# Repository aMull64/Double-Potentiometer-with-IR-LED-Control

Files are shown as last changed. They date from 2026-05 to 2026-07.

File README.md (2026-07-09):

## Problem Formulation
  This project is an extension of a pre-existing product, that being a Logitech Z313 Speaker System with Subwoofer [1]. This speaker system is wired as the output to a Sony TV, one that can be controlled with a wireless controller, but does not respond to volume up or volume down. This is okay because the Logitech speakers do not work with the TV volume. The Logitech speakers control their volume by manually controlling a potentiometer. I would like the ability to control the volume remotely. The TV remote not controlling the TV volume works with us in this case; we can read the IR signals coming from the remote with an IR sensor and adjust the potentiometers to control the volume.
  
  The pre-existing circuit can be seen in Circuit_Board_Scale, and the wires we will be working with can be seen in Circuit_Board_Connectors.
  
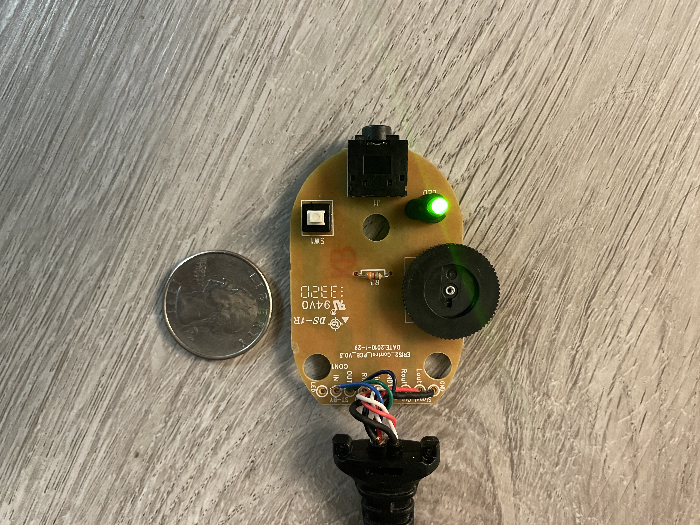
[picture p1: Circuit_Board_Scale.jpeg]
Circuit_Board_Scale: a picture of the circuit next to a quarter

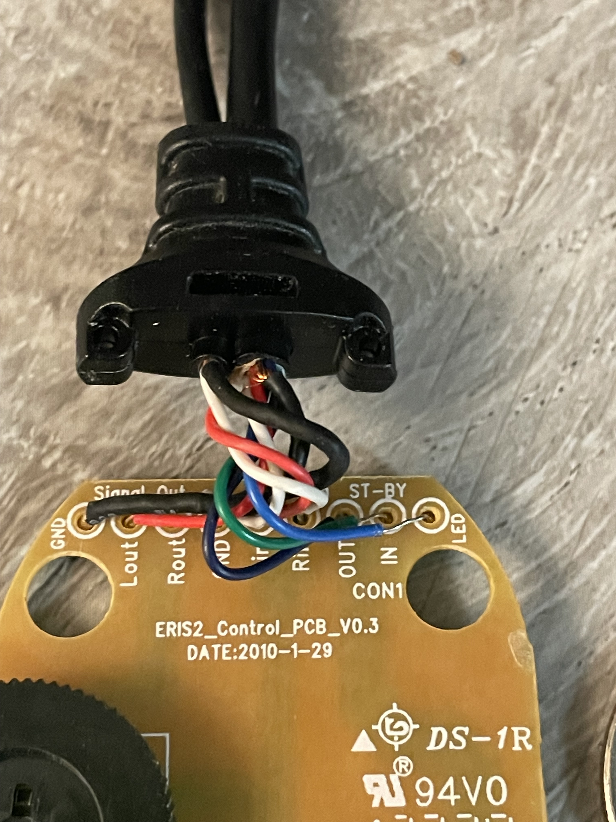
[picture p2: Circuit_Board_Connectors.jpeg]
Circuit_Board_Connectors: a picture of the circuit revealing the pin placements


The pins go as follows: GND, Lout, Rout, GND, Lin, Rin, OUT, IN, LED. Looking at the back reveals that both grounds are connected to each other, creating a common ground.
- Lout and Rout are the left and right channels post-potentiometer
- Lin and Rin are the left and right channels pre-potentiometer
- OUT and IN seem to be used as a way to tell if the system is on or off. They are connected through the dbdt switch and nothing else.
- LED is the power that goes to the LED; we might be able to tap into this power for the integrated circuits. 12V

## Proposed Solution
  In order to read IR signals, we need to include a microcontroller, but in order to choose one, we need to know what else is needed. 2 physical buttons will take the place of the current physical potentiometer, which changes the internal volume variable. And an RGB LED to determine when the system is powered, this can also be used as a debugging tool, changing colors when changing internal variables. 2 digital potentiometers are used to adjust the left and right channel, controlled through I2C. A DBDT switch will be used to control the "power" LED signifier, connect the standby OUT and IN, and introduce power to the rest of the system. The microcontroller in question will need 2 pins for I2C communication (and the ability to do that), 2 pins for manual control (2 buttons), 2 pins for the LED (Blue and Green), and 1 pin for the IR Sensor. In total, we need 7 usable pins, and the ATtiny 404 will fit our case [2]. We will include 2 digital potentiometers that are controlled with I2C 

##  Version 1:
  The first iteration was successful in communicating with the digital potentiometers through I2C. The programming for the experimental stage gave complete control to the RBG LED, the 2 Digital Potentiometers, the ability to read the IR signals from the remote, and the ability to compile the program within the 4kB flash memory limit. This came with the problem of not reading enough datasheets. After further examination of the digital potentiometer datasheet, it does not appreciate negative voltage through the two terminals (which audio covers a range of about [-2.5, 2.5]). This led to some complications and created a design that fundamentally did not work.

##  Version 2:
  The issue was tackled by using a coupling capacitor within a voltage divider to shift the range into a completely positive voltage [0, 5]. The side buttons were removed because they were virtually inaccessible when the casing was completely put on. A different voltage regulator was used that established a 5V rail, which is how the voltage divider was allowed to work.

  

## References
[1] https://www.logitech.com/en-us/shop/p/z313-speaker-system-subwoofer.980-000382 

[2] https://www.digikey.com/en/products/detail/microchip-technology/ATTINY404-SSNR/8594960

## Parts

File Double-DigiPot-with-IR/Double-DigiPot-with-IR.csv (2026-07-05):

Id | Designator | Footprint | Quantity | Designation | Supplier and ref
1 | C1, C2, C3, C4 | C_0805_2012Metric_Pad1.18x1.45mm_HandSolder | 4 | 100n
2 | C5, C6, C7, C8, C9, C10 | C_0805_2012Metric_Pad1.18x1.45mm_HandSolder | 6 | 10u
3 | D1 | LED_D5.0mm-4_RGB_Staggered_Pins | 1 | LED_RKGB
4 | J1 | PinSocket_1x09_P2.54mm_Vertical | 1 | Conn_01x09_Pin
5 | R1, R2, R3 | R_0805_2012Metric_Pad1.20x1.40mm_HandSolder | 3 | 330
6 | R4, R5, R6 | R_0805_2012Metric_Pad1.20x1.40mm_HandSolder | 3 | 4.7k
7 | R7, R8, R9, R10, R11, R12 | R_0805_2012Metric_Pad1.20x1.40mm_HandSolder | 6 | 10k
8 | SW1 | CONN_S2273_APM | 1 | SW_Push_DPDT
9 | TP1, TP2 | TestPoint_Pad_D4.0mm | 2 | TestPoint
10 | TP3 | TestPoint_Pad_D4.0mm | 1 | GNDPoint
11 | U1 | SOIC-14_3.9x8.7mm_P1.27mm | 1 | ATtiny404-SS
12 | U2, U3 | MSOP8_MC_MCH | 2 | MCP4561T-103E/MS
13 | U4 | Vishay_MINICAST-3Pin | 1 | TSOP382xx
14 | U6 | SOT-89-3_Handsoldering | 1 | MC78L05_SOT89

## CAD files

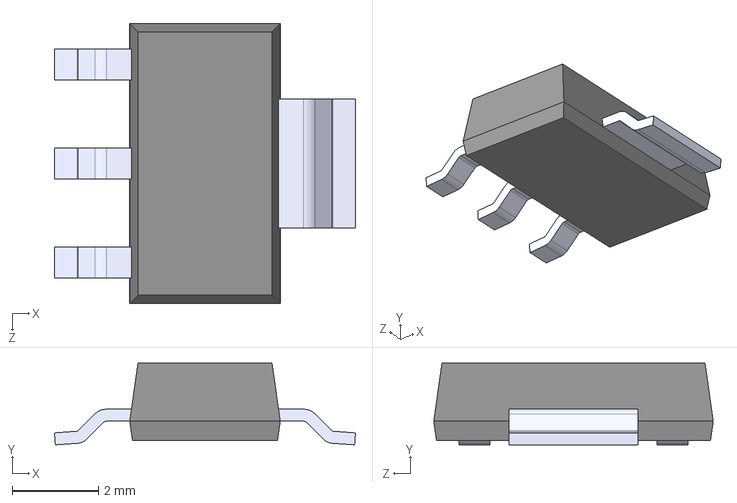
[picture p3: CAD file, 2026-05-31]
Double-DigiPot-with-IR/KiCADv6/TS1117BCW33_RPG.step
7.00 x 1.90 x 6.50 mm

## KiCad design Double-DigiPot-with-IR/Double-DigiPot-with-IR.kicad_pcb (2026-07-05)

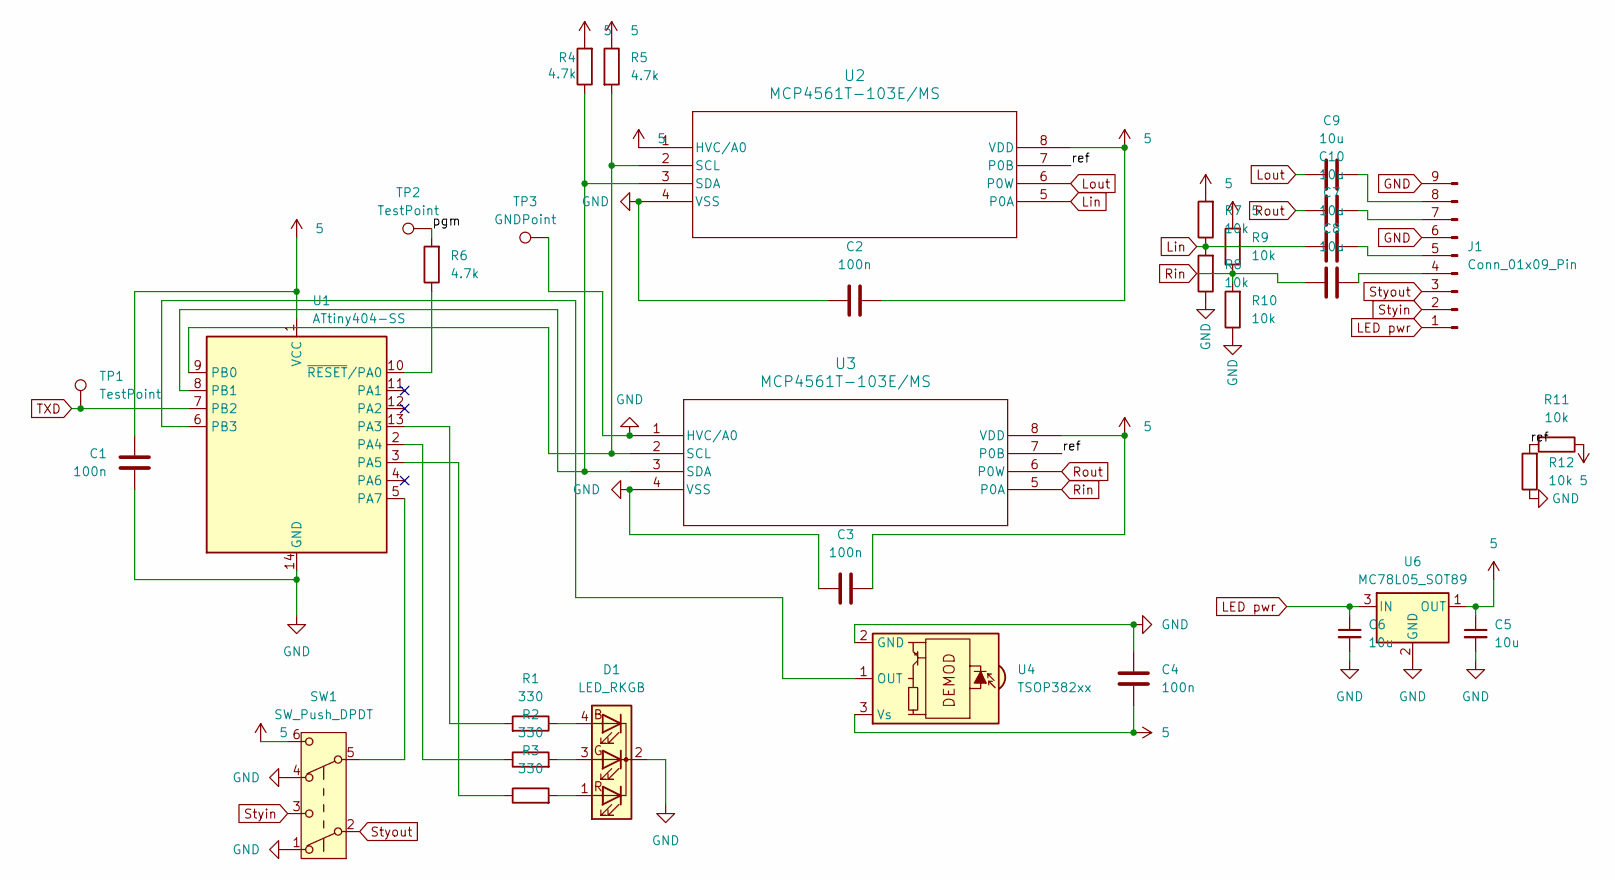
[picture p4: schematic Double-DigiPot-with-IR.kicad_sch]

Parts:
C1, C2, C3, C4: 100n; C_0805_2012Metric_Pad1.18x1.45mm_HandSolder
C5, C6, C7, C8, C9, C10: 10u; C_0805_2012Metric_Pad1.18x1.45mm_HandSolder
D1: LED_RKGB; LED_D5.0mm-4_RGB_Staggered_Pins
J1: Conn_01x09_Pin; PinSocket_1x09_P2.54mm_Vertical
R1, R2, R3: 330; R_0805_2012Metric_Pad1.20x1.40mm_HandSolder
R4, R5, R6: 4.7k; R_0805_2012Metric_Pad1.20x1.40mm_HandSolder
R7, R8, R9, R10, R11, R12: 10k; R_0805_2012Metric_Pad1.20x1.40mm_HandSolder
SW1: SW_Push_DPDT; CONN_S2273_APM
TP1, TP2: TestPoint; TestPoint_Pad_D4.0mm
TP3: GNDPoint; TestPoint_Pad_D4.0mm
U1: ATtiny404-SS; SOIC-14_3.9x8.7mm_P1.27mm
U2, U3: MCP4561T-103E/MS; MSOP8_MC_MCH
U4: TSOP382xx; Vishay_MINICAST-3Pin
U6: MC78L05_SOT89; SOT-89-3_Handsoldering

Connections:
5: C1.1, C2.2, C3.2, C4.1, C5.1, R4.2, R5.1, R7.2, R9.2, R11.1, SW1.6 (C), U1.1 (VCC), U2.1 (HVC/A0), U2.8 (VDD), U3.8 (VDD), U4.3 (Vs), U6.1 (OUT)
/pgm: R6.2, TP2.1 (1_1)
/ref: R11.2, R12.2, U2.7 (P0B), U3.7 (P0B)
GND: C1.2, C2.1, C3.1, C4.2, C5.2, C6.2, D1.2 (K), J1.6, J1.9, R8.1, R10.1, R12.1, SW1.1 (A), SW1.4 (A), TP3.1 (1_1), U1.14 (GND), U2.4 (VSS), U3.1 (HVC/A0), U3.4 (VSS), U4.2 (GND), U6.2 (GND)
LED pwr: C6.1, J1.1, U6.3 (IN)
Lin: C7.1, R7.1, R8.2, U2.5 (P0A)
Lout: C9.1, U2.6 (P0W)
unnamed: D1.4 (BA), R1.1
unnamed: D1.3 (GA), R2.2
unnamed: D1.1 (RA), R3.2
unnamed: C8.2, J1.4
unnamed: C7.2, J1.5
unnamed: C10.2, J1.7
unnamed: C9.2, J1.8
unnamed: R1.2, U1.13 (PA3)
unnamed: R2.1, U1.2 (PA4)
unnamed: R3.1, U1.3 (PA5)
unnamed: SW1.5 (B), U1.5 (PA7)
unnamed: R5.2, U1.9 (PB0), U2.2 (SCL), U3.2 (SCL)
unnamed: R4.1, U1.8 (PB1), U2.3 (SDA), U3.3 (SDA)
unnamed: U1.6 (PB3), U4.1 (OUT)
unnamed: R6.1, U1.10 (~RESET/PA0)
Rin: C8.1, R9.1, R10.2, U3.5 (P0A)
Rout: C10.1, U3.6 (P0W)
Styin: J1.2, SW1.3 (C)
Styout: J1.3, SW1.2 (B)
TXD: TP1.1 (1_1), U1.7 (PB2)

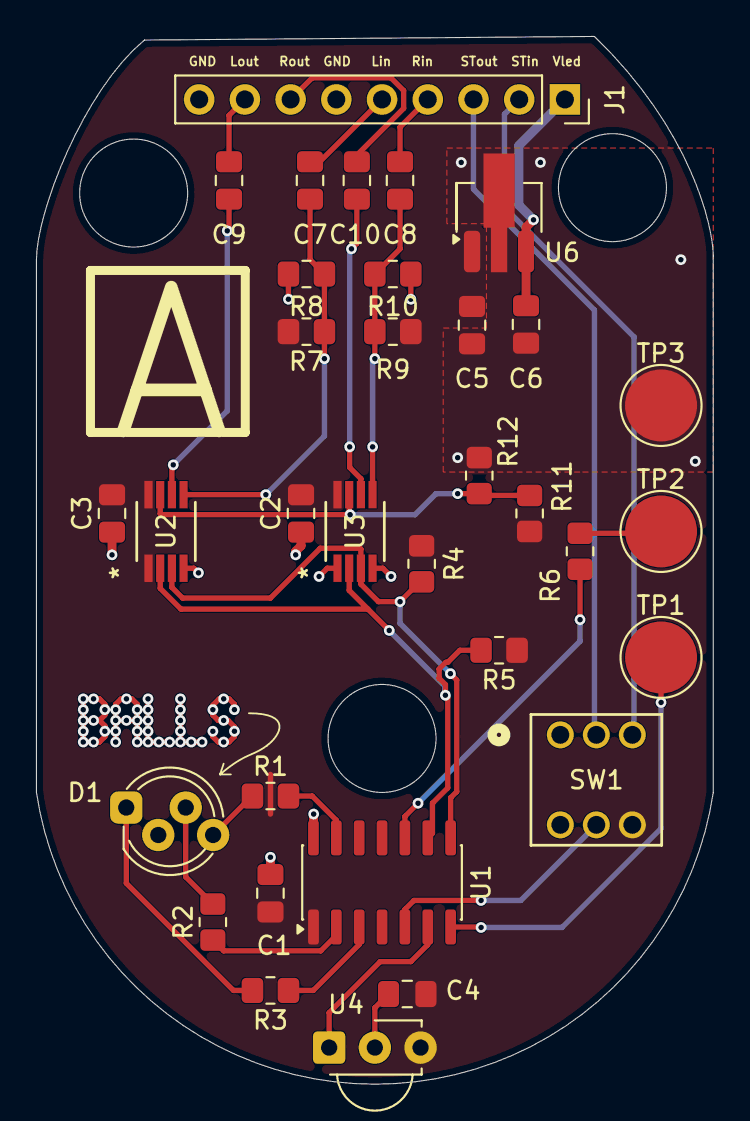
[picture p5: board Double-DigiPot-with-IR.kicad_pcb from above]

Board: 2 copper layers, 37.6 x 58.2 mm, 33 parts (0 on the bottom side), 27 nets.

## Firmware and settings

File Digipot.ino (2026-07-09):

#include <Wire.h>
#include <avr/io.h>
#include <avr/interrupt.h>

//#define DEBUG

#define POWER_STATUS_PIN (8)
#define RED_LED_PIN (2)
#define BLUE_LED_PIN (3)
#define SENSOR_PIN (4)

#define RED_LED_bm (PIN4_bm)
#define BLUE_LED_bm (PIN5_bm)

#define SENSOR_bm (PIN3_bm)
#define SENSOR_pos (3)

#define MIN_SAMPLES_0 (1)
#define MIN_SAMPLES_1 (5)
#define MAX_SAMPLES_0 (4)
#define MAX_SAMPLES_1 (8)
#define MIN_SAMPLES_START (9)
#define MAX_SAMPLES_START (50)

#define NUM_BITS (12)

#define VOL_UP_CMD (0x490)
#define VOL_DOWN_CMD (0xC90)
#define VOL_MUTE (0x290)
#define IR_DOWNTIME (500)

#define LED_ON_TICKS (1000)
#define MAX_COMBO (30)

volatile uint8_t vol = 1;
volatile uint8_t mute_flag = 0;
volatile uint8_t sent_vol = 0;

// Your register address, which can be found on your IC's datasheet
#define SUB_0_ADDR 0x2E //please correct me if wrong, datasheet says '0101 11'b + A0 = 0010 111 (0 or 1)
#define SUB_1_ADDR 0x2F
#define WRITE_CMD 0x00

/*Pinouts:
(11)PA0 = programming Pin
(8)PA1 = Power Data Input
(0)PA4 = LED Red
(1)PA5 = LED Blue
(2)PA6 = Volume Up Pushbutton
(3)PA7 = Volume Down Pushbutton

(7)PB0 = SCL
(6)PB1 = SDA
(5)PB2 = TestPoint
(4)PB3 = IRLED
*/

ISR(TCA0_OVF_vect) {
    static volatile uint8_t samp_count = 0;
    static volatile uint8_t bit_count = 0;
    static volatile uint16_t cmd_buffer = 0x00;

    static volatile uint16_t red_led_on_ticks = 0;
    static volatile uint16_t blue_led_on_ticks = 0;

    static volatile uint16_t on_ticks = 0;
    static volatile uint8_t combo_meter = 0;

    static volatile uint16_t last_cmd = 0;

    uint8_t sensor_state = (PORTB.IN & SENSOR_bm) >> SENSOR_pos;

    if (sensor_state) {
      // Check to see if we just got high
      if(on_ticks <= IR_DOWNTIME){
        ++on_ticks;
        if(on_ticks == IR_DOWNTIME){
          combo_meter = 0;
        }
      }

      if (samp_count) {
        if (bit_count <= NUM_BITS)
          ++bit_count;

        if (samp_count > MIN_SAMPLES_0 && samp_count <= MAX_SAMPLES_0) {
          // I guess we do nothing
        }
        else if (samp_count > MIN_SAMPLES_1 && samp_count <= MAX_SAMPLES_1) {
          cmd_buffer |= (1 << (NUM_BITS - bit_count));
        }
        else if(samp_count > MIN_SAMPLES_START && samp_count <= MAX_SAMPLES_START) {
          // We got a start bit
          cmd_buffer = 0x00;
          bit_count = 0;
        }

        // Check how many bits we got
        if (bit_count == NUM_BITS) {
          if (last_cmd == cmd_buffer) {
            if (combo_meter < MAX_COMBO)
              ++combo_meter;
          }

          else {
            combo_meter = 0;
          }

          last_cmd = cmd_buffer;

          if (cmd_buffer == VOL_UP_CMD && vol < 255) {
            mute_flag = 0;

            if (combo_meter == MAX_COMBO) {
              vol = vol < 250 ? vol + 5 : 255;
            } else ++vol;

            red_led_on_ticks = LED_ON_TICKS;
          }

          else if (cmd_buffer == VOL_DOWN_CMD && vol > 0) {
            mute_flag = 0;

            if (combo_meter == MAX_COMBO) {
              vol = vol > 5 ? vol - 5 : 0;
            } else --vol;

            blue_led_on_ticks = LED_ON_TICKS;
          }

          else if (cmd_buffer == VOL_MUTE) {
            if (combo_meter == 1) {
              mute_flag = !mute_flag;
            }
          }
            
#ifdef DEBUG
          Serial.print("Command: 0x");
          Serial.print(cmd_buffer, HEX);
          Serial.print(" Volume: ");
          Serial.println(vol);
#endif
        }
      }

      if (red_led_on_ticks) {
        --red_led_on_ticks;
        PORTA.OUTSET = RED_LED_bm;
      } else if (mute_flag) {
        PORTA.OUTSET = RED_LED_bm;
      }
      else {
        PORTA.OUTCLR = RED_LED_bm;
      }
      
      if (blue_led_on_ticks) {
        --blue_led_on_ticks;
        PORTA.OUTSET = BLUE_LED_bm;
      } else {
        PORTA.OUTCLR = BLUE_LED_bm;
      }

      // Clear this for future samples
      samp_count = 0;
    }

    else {
      on_ticks = 0;
      ++samp_count; // It's faster this way trust me
    }
    
    // Clear the overflow interrupt flag to allow the next interrupt
    TCA0.SINGLE.INTFLAGS = TCA_SINGLE_OVF_bm;
}

void timer_init() {
  TCA0.SINGLE.PER = 250; // Hopefully 200us?
  TCA0.SINGLE.CTRLA = TCA_SINGLE_CLKSEL_DIV16_gc | TCA_SINGLE_ENABLE_bm;
  TCA0.SINGLE.INTCTRL = TCA_SINGLE_OVF_bm;
  sei();
}

void setup() {
	Wire.begin();
  Serial.begin(115200);

  pinMode(SENSOR_PIN, INPUT);
  pinMode(POWER_STATUS_PIN, INPUT);
  pinMode(RED_LED_PIN, OUTPUT);
  pinMode(BLUE_LED_PIN, OUTPUT);
  timer_init();
  
  Serial.println("Sony IR volume control with I2C digipot");
  Serial.print("CPU Frequency: ");
  Serial.print(F_CPU);
}

void loop() {

  uint8_t next_vol = mute_flag ?   0 : vol;
  if(next_vol != sent_vol){
    sent_vol = next_vol;
  
    // Write volume data
    Wire.beginTransmission(SUB_0_ADDR);  
    Wire.write(WRITE_CMD); 
    Wire.write(sent_vol);
    Wire.endTransmission();  

    Wire.beginTransmission(SUB_1_ADDR);  
    Wire.write(WRITE_CMD); 
    Wire.write(sent_vol);
    Wire.endTransmission();  

    Serial.print(" Volume: ");
    Serial.print(sent_vol);
    Serial.print(", Mute Flag: ");
    Serial.println(mute_flag);

  }
  
  delay(10);
}

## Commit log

2026-05-14 2 pictures of the circuit for scale and clarity
2026-05-31 Updated PCB
    [Double-DigiPot-with-IR.kicad_pcb, Double-DigiPot-with-IR.kicad_sch, TS1117BCW33_RPG.step]
2026-07-03 MEGA UPDATE (Redesign) (It might work now)
    [Double-DigiPot-with-IR.kicad_pcb, Double-DigiPot-with-IR.kicad_sch]
2026-07-05 Update PCB so we can verify that everything got updated
    [Double-DigiPot-with-IR.kicad_pcb]
2026-07-05 Digipot V2!!!!
    [Double-DigiPot-with-IR-B_Cu.gbr, Double-DigiPot-with-IR-B_Mask.gbr, Double-DigiPot-with-IR-B_Paste.gbr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]
